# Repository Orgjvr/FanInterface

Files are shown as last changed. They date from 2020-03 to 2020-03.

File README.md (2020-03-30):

# FanInterface
This acts as an interface to a speed controlled Fan, and simulate a specific speed. I used it for a CyberPower OLS1000EC UPS which needs a fan running at about 4000 rpm and could only get a slower replacement.

## Background
After a power failure, my UPS did not stop beeping. Then I realised that it does not start up anymore. After investigating, I found that the fan failed, and as a safety feature, the UPS does not switch on. After googling a bit, I found the datasheet for the fan: a DA08025B12HF manufactured by Shenzen Huaxia Henstai Electronic Co. I also found someone else who did a similar fan change. His solution was a NE555 outputting a 137Hz square wave (See comment 15). I did not want to lose the fan failure detection functionality, so I decided to build this interface. 

## So what is this?
This interface connects between a fan controller and a fan, and lets you output a specific speed to the controller independant of the connected fan speed, while still monitoring the connected fan speed. As long as the fan speed is above a set limit, it will output the required pulses to the controller. But as soon as the fan speed drop below the limit, then it will also stop the simulated fan speed and the original fan controller can decide what to do with the failure. 

Here is a picture of the final prototype on a breadboard:
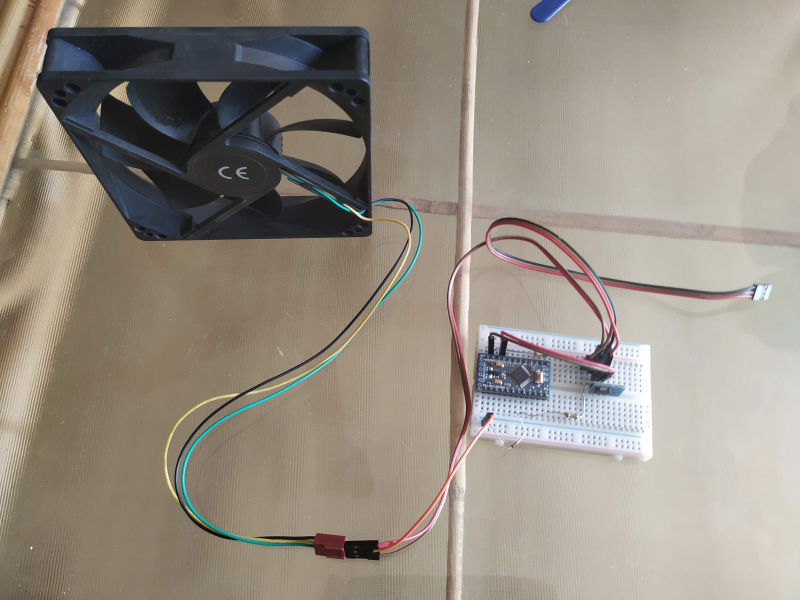
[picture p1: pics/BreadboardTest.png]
Picture of the final prototype on a breadboard


Here is a picture of the top of the fan interface as well as the bottom:
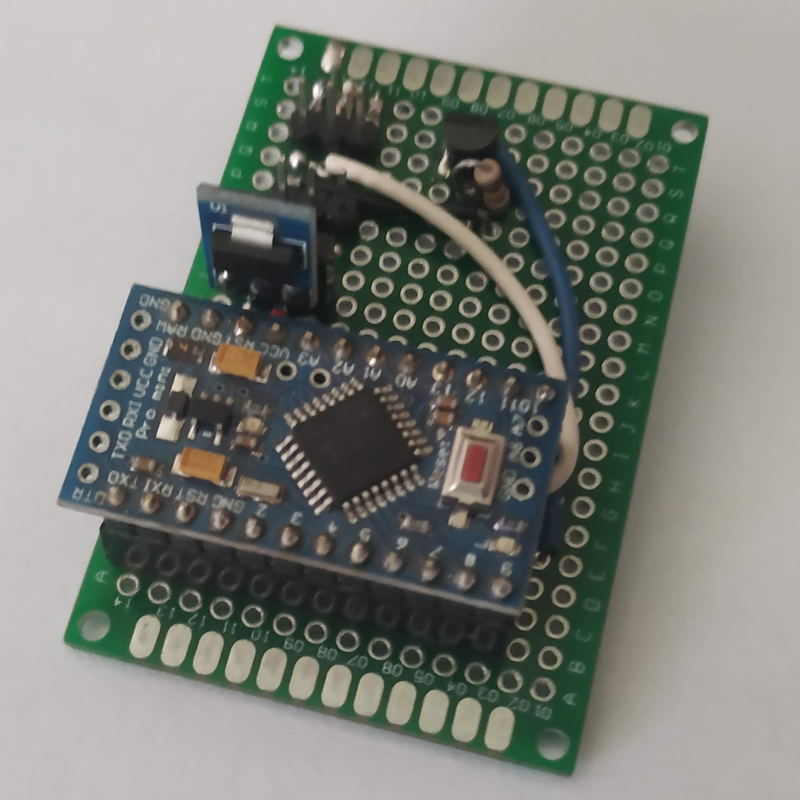
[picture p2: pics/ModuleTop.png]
The Top of the module

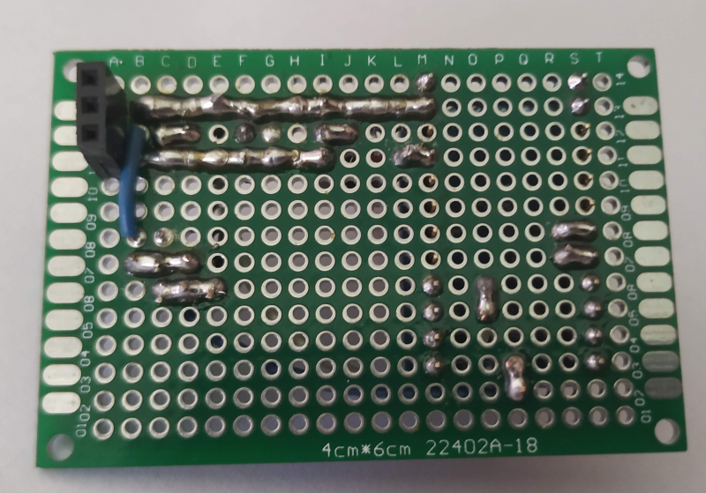
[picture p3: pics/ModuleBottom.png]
The Bottom of the module


Here is the fan interface working inside the UPS:
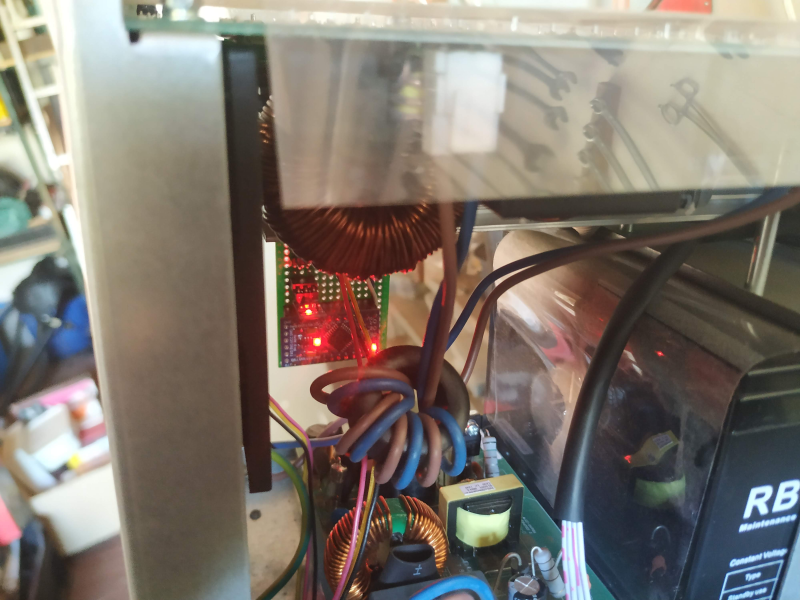
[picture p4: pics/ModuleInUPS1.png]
Fan interface inside UPS

Another fan interface inside UPS


And last but not least, here is a picture of the broken original fan:
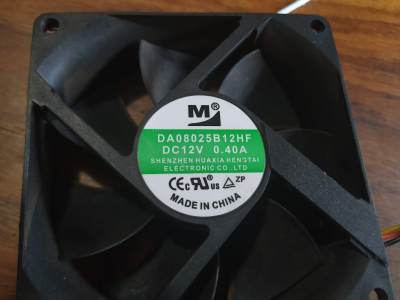
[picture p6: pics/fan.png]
Broken Original fan


## Did I try anything else?
Initially I tried a replacement fan, but as it was outputting pulses at too slow a rate, it still did not work. Next I thought to build this solution with an ESP8266-01 as I had loads of them available, but the power supply to the fan was not stable enough to keep the ESP8266 up and running. After changing to a Arduino Pro Mini, I had a stable solution.

For those who wants a simple approach without failure warning, have a look at the comment by Frank in #12 on this blog: https://www.ispcolohost.com/2015/02/27/quieting-down-the-noisy-cyberpower-ol3000rtxl2u-ups/

## How to build the Fan Interface?

### What do I need?
- An arduino Pro Mini 3.3V (Or any similar mcu)
- PSU. I used a AMS1117 based psu to convert from 12V to 3.3V: https://www.banggood.com/5V-To-3_3V-DC-DC-Step-Down-Power-Supply-Buck-Module-AMS1117-800MA-p-933674.html Most likely this is unneeded, but I had it because of the ESP8266-01 I used initially.
- 2 x 3 Pin Male connectors
- 3 Pin Female connector
- 2 x 12 Pin Female connector (Optional) for Arduino Pro Mini.
- 2N7000 Mosfet
- 150 ohm Resistor
- 100K ohm Resistor
- 1N4148 diode

### Schematic
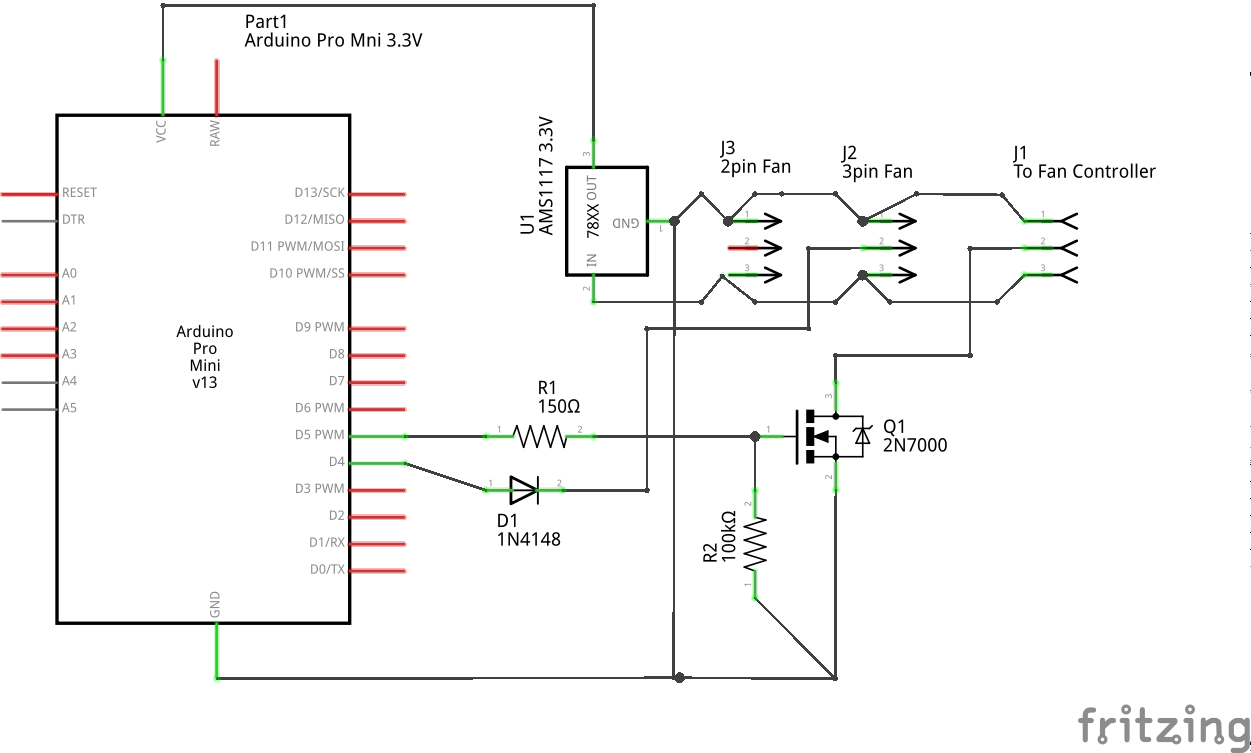
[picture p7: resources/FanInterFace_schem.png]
Schematic


### Code
The code is available in the https://github.com/Orgjvr/FanInterface/blob/master/FanSimulator/src/main.cpp file. I am using the excellent PlatformIO, and I also included the platformio.ini file as well if you want to use the same mcu. Otherwise adjust it as you need.

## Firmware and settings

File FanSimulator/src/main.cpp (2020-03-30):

#include <Arduino.h>
#define HASLED

#define FET_PIN 5 //14 //Define FET pin to simulate fan speed
#define FAN_SENSE_PIN 4 //14 //Define pin on which to sense the fan speed

#define CONST_TIME 4 //125hz = 4ms for on and 4ms for off
#define CONST_TIME_CHECK_FAN 1250 //Check only every 1250/125hz=10 seconds if fan is still running.

#ifdef HASLED
  #define LED_PIN 13 //2 //Define blinking LED pin
#endif

unsigned long pulseHigh; // Integer variable to capture High time of the incoming pulse
unsigned long pulseLow; // Integer variable to capture Low time of the incoming pulse
float pulseTotal; // Float variable to capture Total time of the incoming pulse
float frequency; // Calculated Frequency
bool FanOK=true; // Used to signal Fan troubles 

int Countdown = 0;  

void setup() {
  // put your setup code here, to run once:
  pinMode(FET_PIN, OUTPUT); // Initialize the FET pin as an output
  pinMode(FAN_SENSE_PIN, INPUT_PULLUP); // Initialize the FAN_SENSE pin as an input with a pullup
  #ifdef HASLED
    pinMode(LED_PIN, OUTPUT); // Initialize the FET pin as an output
    digitalWrite(LED_PIN, LOW); // Turn the LED OFF
  #endif
}

void loop() {
  //We check if the fan is turning, but we only check if it was in a failed state or if a period like 10 seconds passed 
  //   otherwise it interferes too much with the output pulse.
  if (Countdown <= 0 || FanOK == false) {
    pulseHigh = pulseIn(FAN_SENSE_PIN,HIGH, 200000);
    pulseLow = pulseIn(FAN_SENSE_PIN,LOW, 200000);
    if (pulseHigh == 0) pulseHigh = 60000000;
    if (pulseLow == 0) pulseLow = 60000000;

    pulseTotal = pulseHigh + pulseLow; // Time period of the pulse in microseconds
    frequency=1000000/pulseTotal; // Frequency in Hertz (Hz)

    if (frequency >= 30) {
      FanOK = true;
    } else {
      FanOK = false;
    }
    Countdown = CONST_TIME_CHECK_FAN;
  } else {
    Countdown--;
  }
  
  if (FanOK) {
    #ifdef HASLED
      digitalWrite(LED_PIN, HIGH); // Turn the LED on
    #endif
    digitalWrite(FET_PIN, LOW); // Turn the FET on (Note that LOW is the voltage level)
    delay(CONST_TIME); 
    digitalWrite(FET_PIN, HIGH); // Turn the FET off by making the voltage HIGH
    delay(CONST_TIME);
  } else {
    #ifdef HASLED
      digitalWrite(LED_PIN, LOW); // Turn the LED off
    #endif
  }
}

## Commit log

2020-03-30 Added schematic
    [FanInterFace.fzz]
2020-03-30 Update README.md
    Added schematic
